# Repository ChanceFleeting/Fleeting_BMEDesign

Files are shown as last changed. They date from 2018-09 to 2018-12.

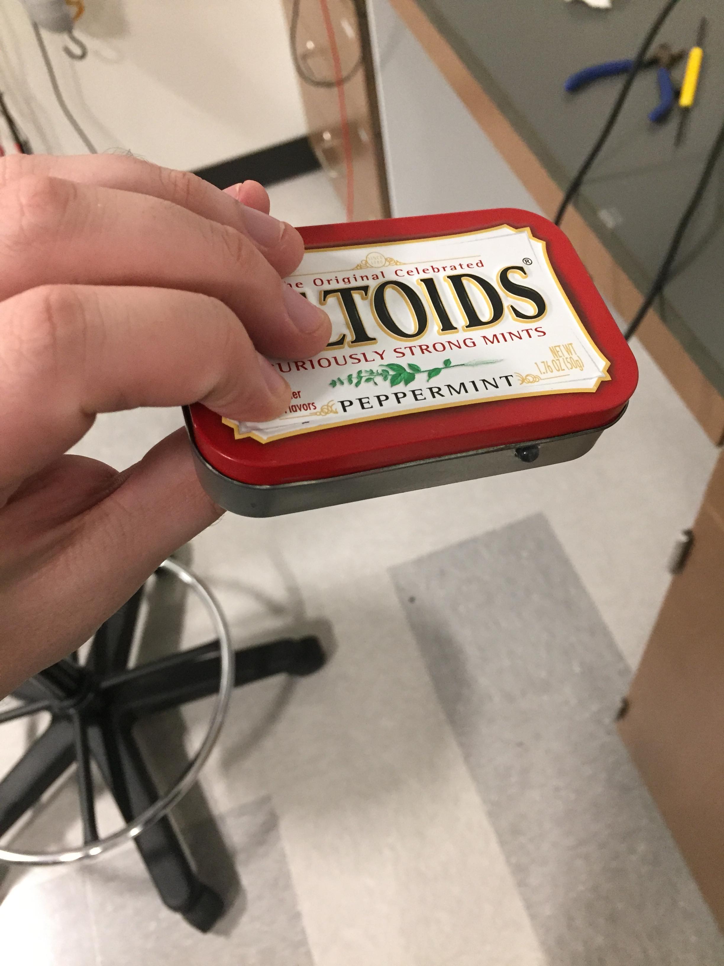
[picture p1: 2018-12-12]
Semester1Design/Testing/47689593_1096601613842765_1074258826393288704_n.jpg

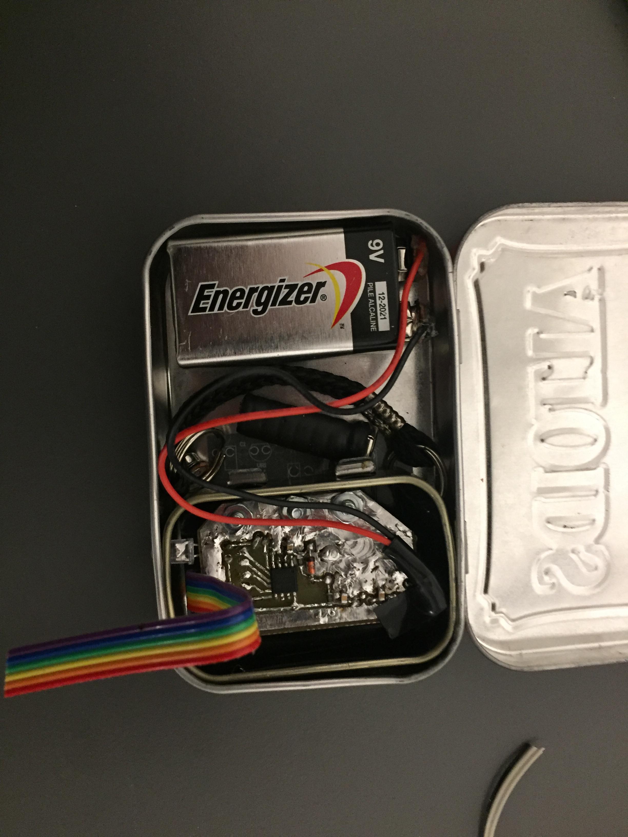
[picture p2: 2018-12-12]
Semester1Design/Testing/48209552_262310304441675_4003035783320567808_n.jpg

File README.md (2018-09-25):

# Fleeting_BMEDesign
A repo to contain my work for Dr. Palmeri's 2-semester BME design course (BME590L.03 F'18; BME464 Sp'19).
 
Semester 1 Design: Design Skills Project (Variable Light Intensity) 

    Functional Specifications
        LED light that is button-activated to switch between the following operating modes:
            Off
            Brightest
            Intermediate Brightness
            Least Bright
            Flashing @ 2 Hz
        Self-contained device with LED and button exposed.
        Extra credit possibilities:
            Battery life indicator
            Waterproof enclosure
            You tell us!

    Constraints

        Run on single battery up to 9 V
        Electronics connected to a single PCB (can be single- or double-sided)
        Cannot weight more than 1 lb
        Cannot have a single dimension > 6 in
        Cannot cost more than $50 to duplicate unit
        Battery must be easily replaceable

    Evaluation

        Minimize weight

        Minimize size

        Maximize Brightest mode

        Minimize power draw / maximize battery life

        Survive 3 foot drop with battery installed

        Create-and-maintain a GitHub project repository to maintain version history of:
            Mechanical CAD (PDFs + more)
            Electronic CAD (PDFs + more)
            Software
            Testing data
            Design history / notes
            Specification sheets
            Usage notes (README.md)
            Kanban board / Issues / Milestones

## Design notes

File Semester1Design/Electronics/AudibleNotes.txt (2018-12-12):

Changes made:

The TO92s were soldered below deck to allow for space ontop of device.
Ribbon cable has been replaced by female headers for reprogramability
100-Ohm resistor has been used as shunt to LED

EC:
Reprogramability
Modular design (minibattery broke (I sat on it))
Water proof (Still need to pot it in Nylon and coat the outside.
Thematic (Altoids please sponsor me)

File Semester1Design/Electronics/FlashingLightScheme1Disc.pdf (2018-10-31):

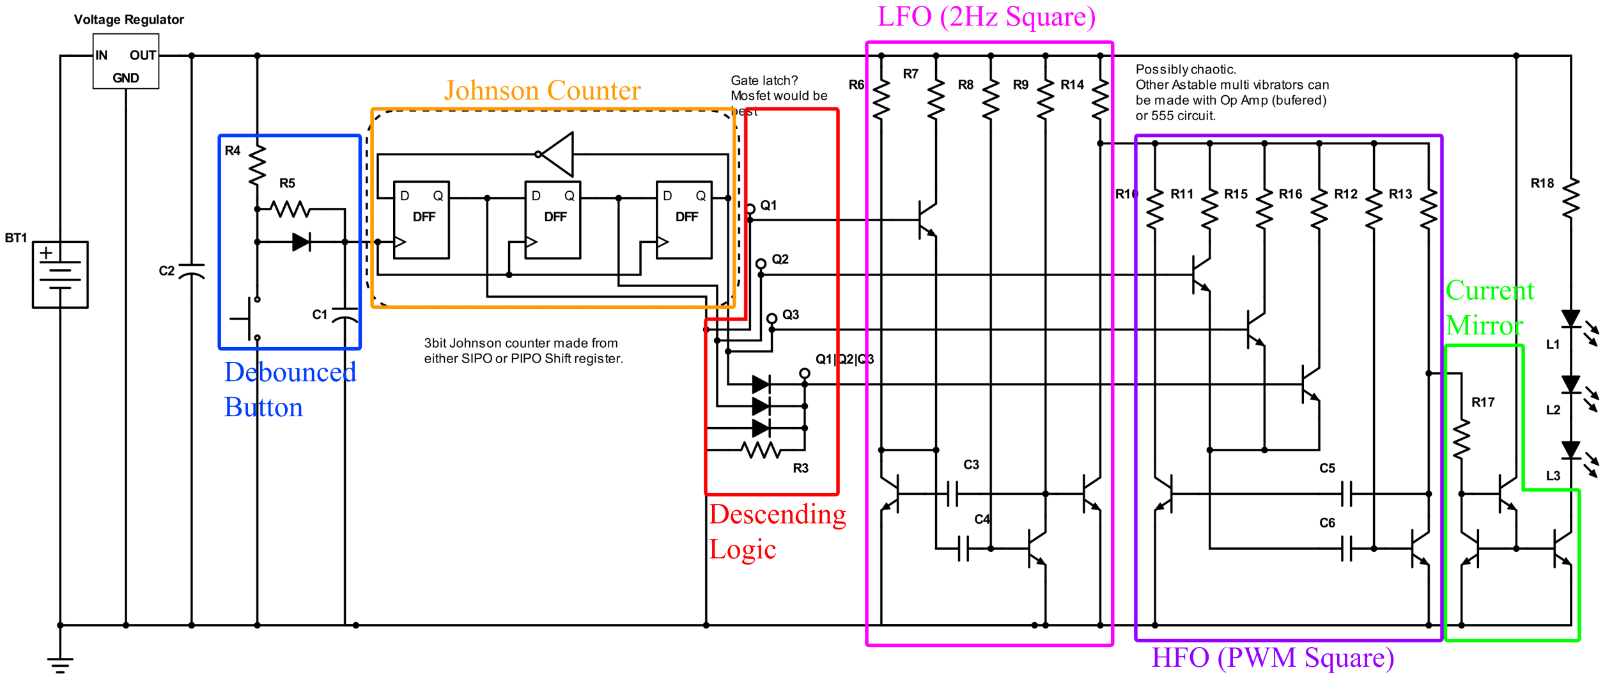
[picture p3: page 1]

Debounced
Button

HFO(PWMSquare)

Current
Mirror

JohnsonCounter

Descending
Logic

LFO(2HzSquare)

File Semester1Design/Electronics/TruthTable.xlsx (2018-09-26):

 |  |  | Truth Table: Descending logic from Manually Itterated Johnson Ring counter
 |  | Counter |  |  | Controls
 | State | Q1 | Q2 | Q3 | On/off | L 1 | L 2 | L 3 | Osc
off | 0 | 0 | 0 | 0 | 0 | 0 | 0 | 0 | 0
Low | 1 | 1 | 0 | 0 | 1 | 1 | 0 | 0 | 1
Mid | 2 | 1 | 1 | 0 | 1 | 1 | 1 | 0 | 1
High | 3 | 1 | 1 | 1 | 1 | 1 | 1 | 1 | 1
2HzH | 4 | 0 | 1 | 1 | 1 | 1 | 1 | 1 | 0
2HzM | 5 | 0 | 0 | 1 | 1 | 1 | 0 | 1 | 0
 |  | Descending Logic |  |  | Q1|Q2|Q3 | Q1|Q2|Q3 | Q2 | Q3 | Q1

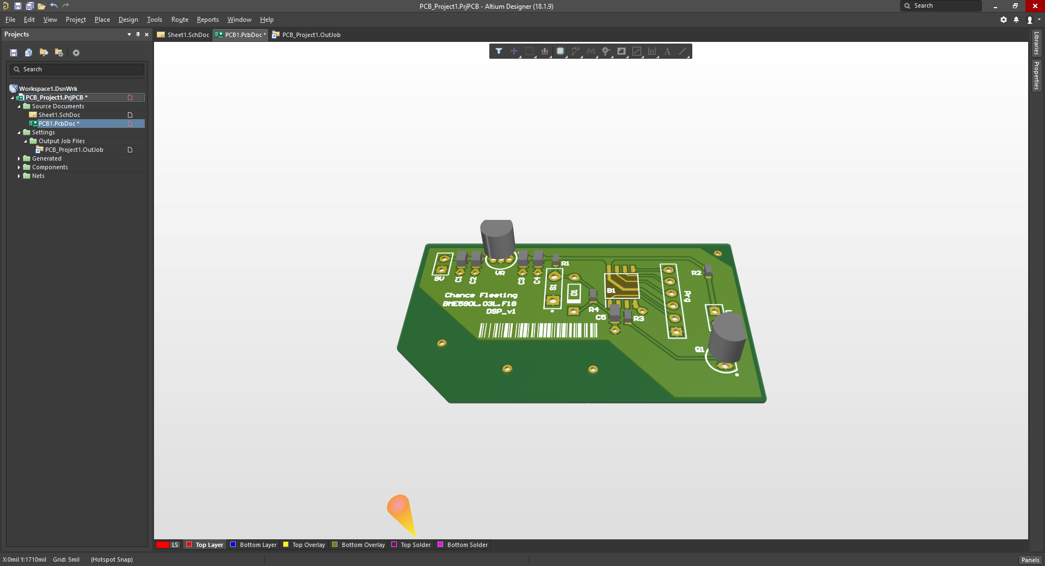
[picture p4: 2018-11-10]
Semester1Design/Electronics/PCB/PCB_3D_Front.PNG

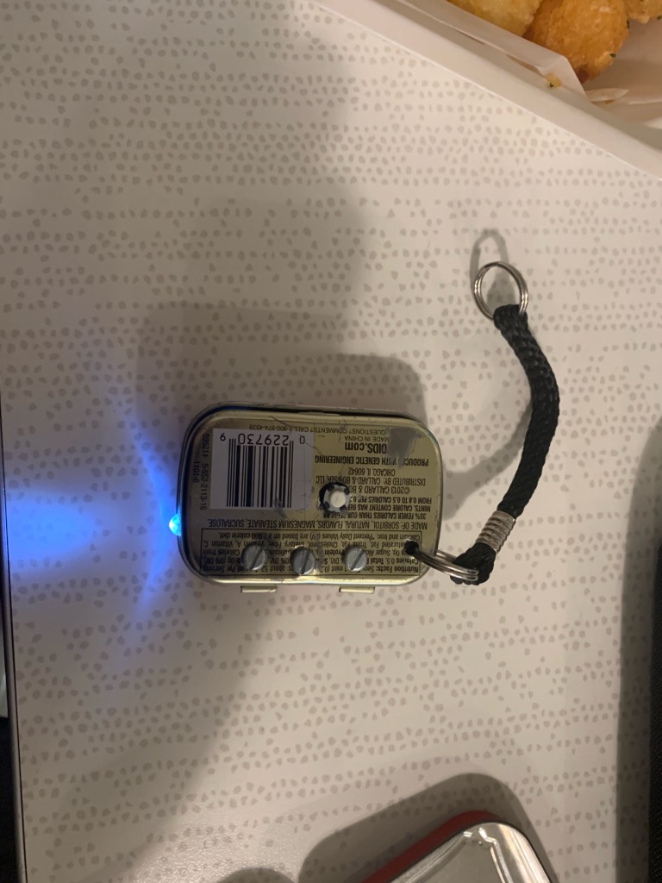
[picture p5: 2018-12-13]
Semester1Design/Testing/Final_Design_Small_3.jpg

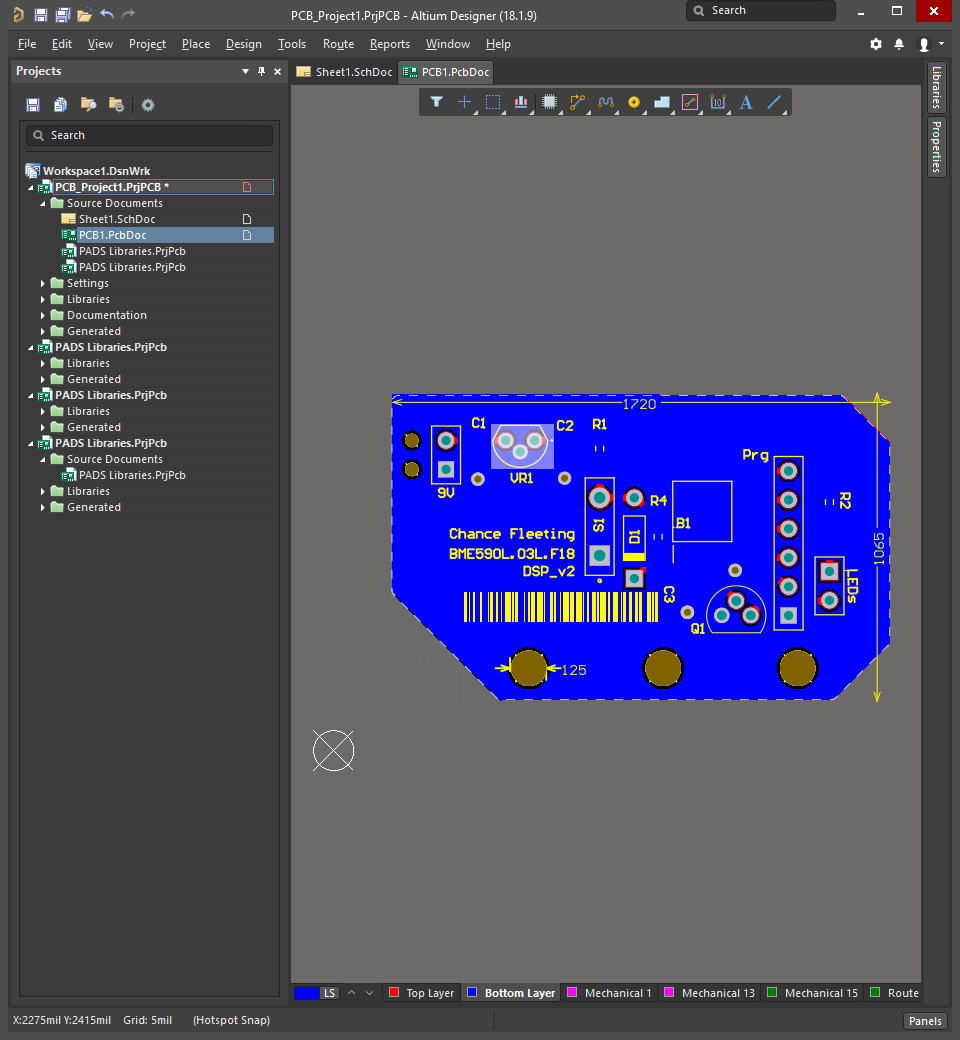
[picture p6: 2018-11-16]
Semester1Design/Electronics/PCB/PCB_2D_Back_smaller.PNG

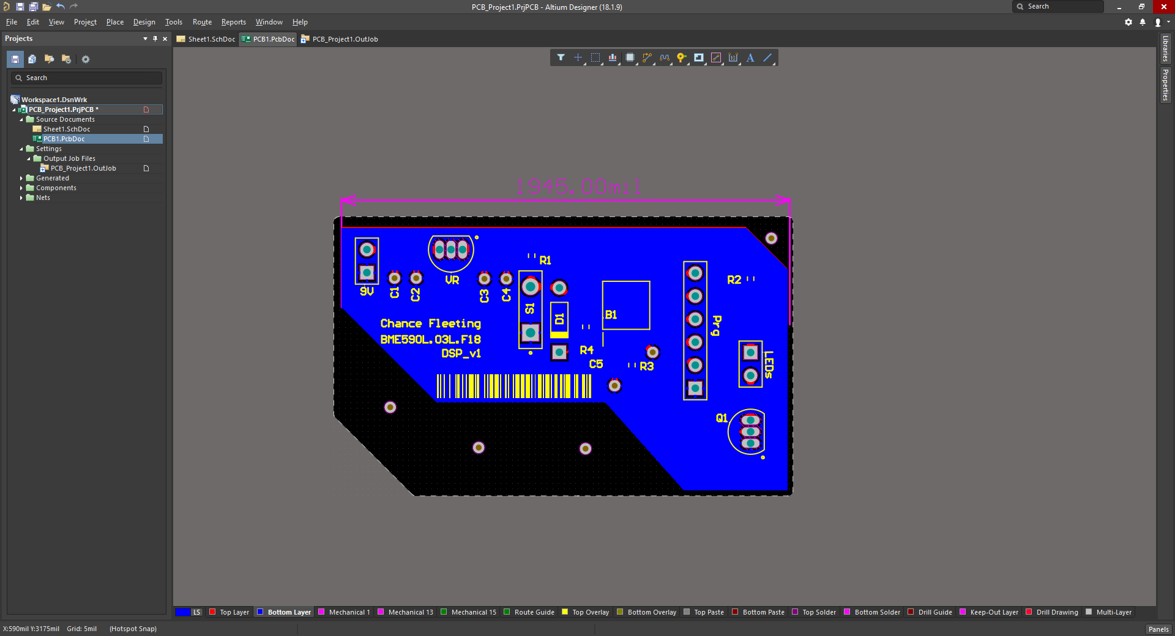
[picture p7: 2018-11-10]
Semester1Design/Electronics/PCB/PCB_2D_Back.PNG

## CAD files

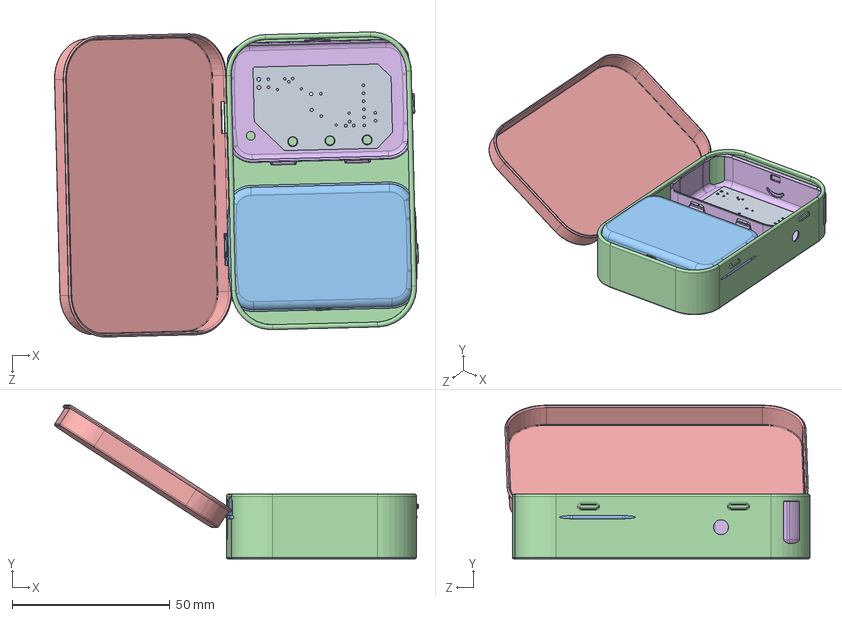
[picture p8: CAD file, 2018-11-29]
Semester1Design/Mechanical/CasingExploration/Assem1.SLDASM
115.5 x 48.8 x 96.8 mm
Board
9V
smallLid
Bottom
Lid
smallBottomCut

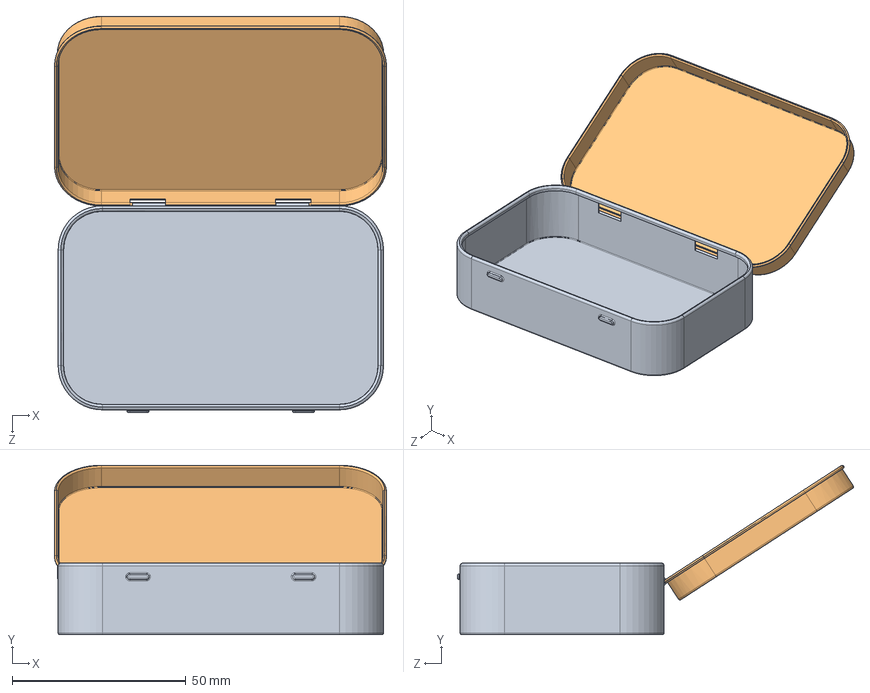
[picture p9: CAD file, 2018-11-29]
Semester1Design/Mechanical/CasingExploration/LargeAltoidsbox.SLDASM
95.6 x 48.8 x 114.1 mm
Bottom
Lid

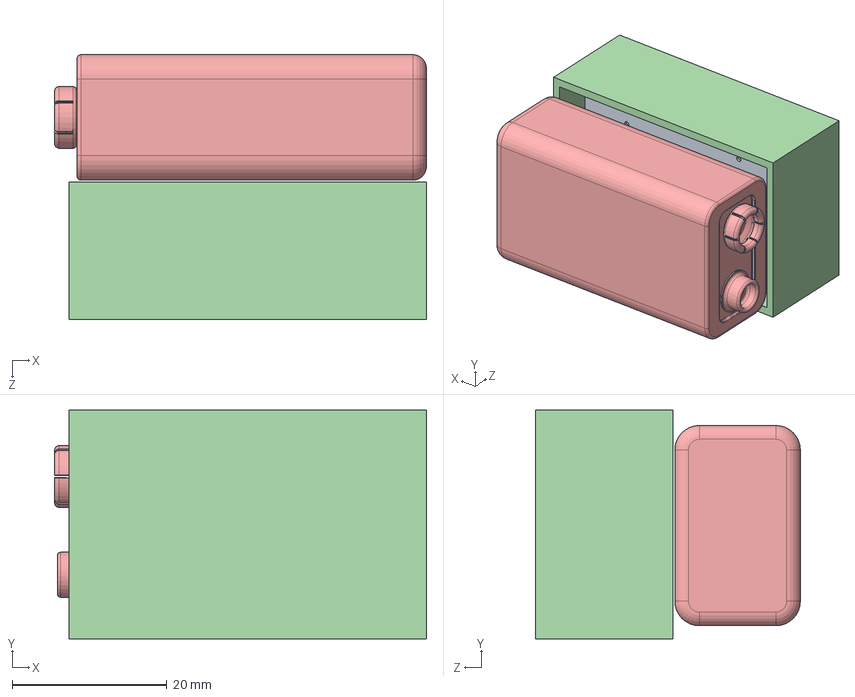
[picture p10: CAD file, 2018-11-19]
Semester1Design/Mechanical/PCB1.SLDASM
48.1 x 29.6 x 34.3 mm
Board
Extruded x 3
Extruded_2 x 3
9volt

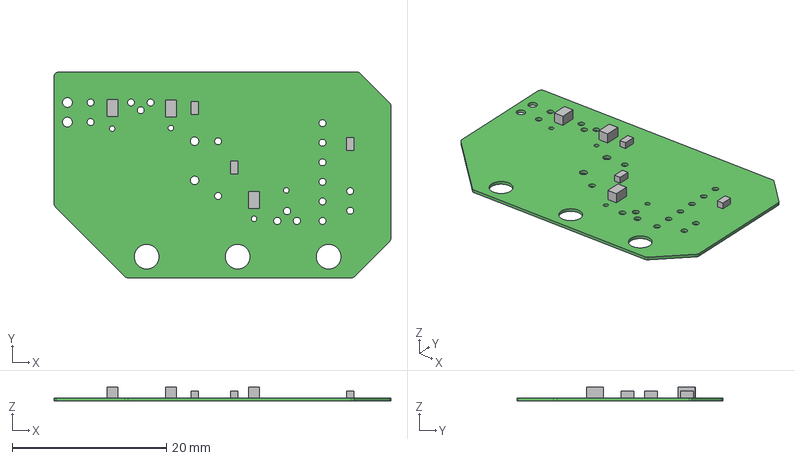
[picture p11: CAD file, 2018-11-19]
Semester1Design/Electronics/PCB/ECAD files/PCB1.step
43.7 x 26.7 x 1.81 mm
Board
Extruded x 6

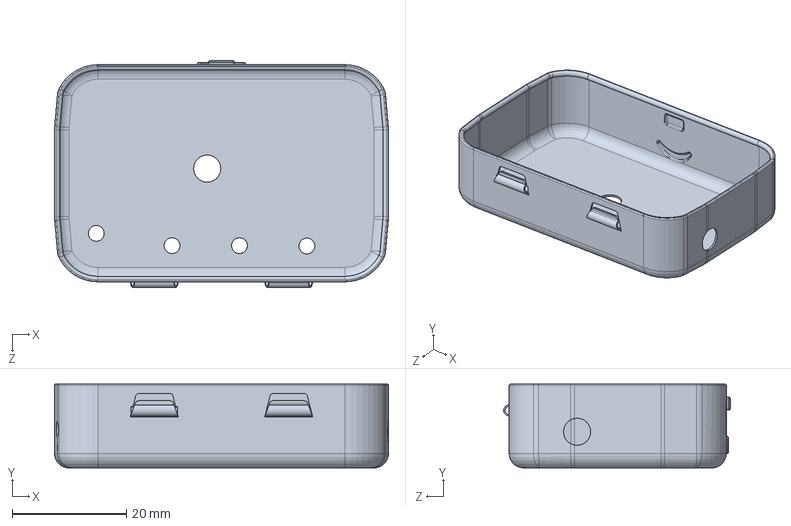
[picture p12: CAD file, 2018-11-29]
Semester1Design/Mechanical/CasingExploration/smallBottomCut.SLDPRT
58.5 x 14.7 x 39.7 mm

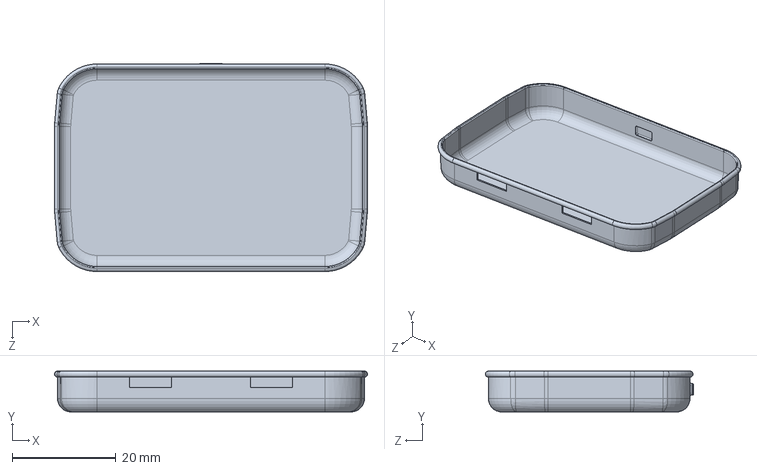
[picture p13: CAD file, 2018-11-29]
Semester1Design/Mechanical/CasingExploration/smallLid.SLDPRT
60.4 x 7.87 x 40.2 mm

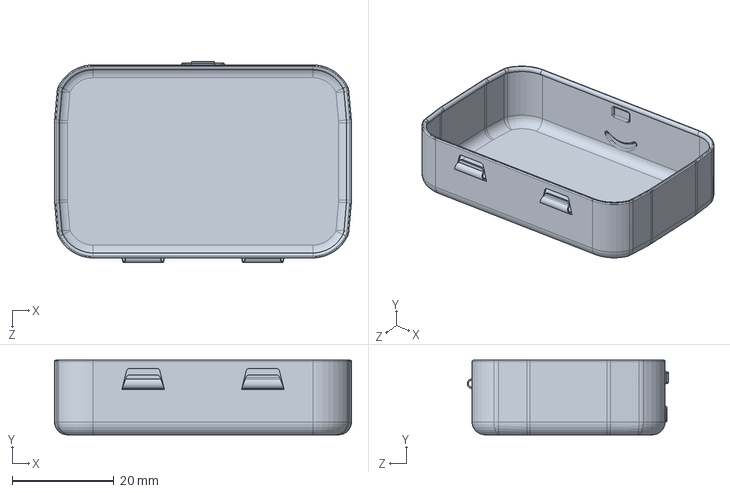
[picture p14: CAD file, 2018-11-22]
Semester1Design/Mechanical/CasingExploration/smallBottom.SLDPRT
58.5 x 14.7 x 39.7 mm

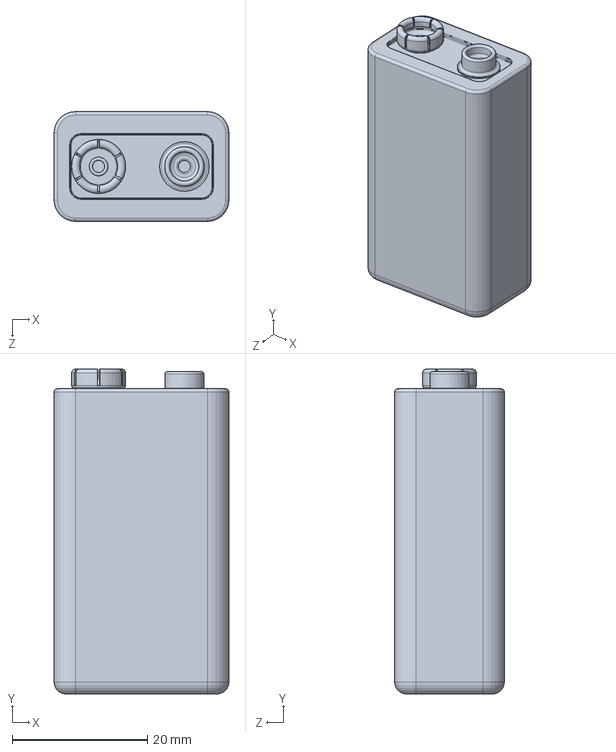
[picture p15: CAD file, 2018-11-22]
Semester1Design/Mechanical/CasingExploration/9V.SLDPRT
25.9 x 48.1 x 16.3 mm

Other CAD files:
Semester1Design/Mechanical/R2.sldasm
Semester1Design/Mechanical/C2.sldasm
Semester1Design/Mechanical/R1.sldasm
Semester1Design/Mechanical/C1.sldasm
Semester1Design/Mechanical/R4.sldasm
Semester1Design/Mechanical/C3.sldasm
Semester1Design/Mechanical/Board.sldprt
Semester1Design/Mechanical/Extruded.sldprt
Semester1Design/Mechanical/Extruded_2.sldprt
Semester1Design/Mechanical/5803305728.sldasm
Semester1Design/Mechanical/5803305536.sldasm
Semester1Design/Mechanical/SpecialAssembly.SLDDRW

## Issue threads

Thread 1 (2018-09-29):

Interface Controls: style and count

ChanceFleeting, 2018-09-29:
In the instruction it is stated that the variable light will need to be “button-activated to switch between [five] operating modes“. Does this mean that we are expected to have a _single_ button as the full control interface rather than individual controls or are we allowed to use separate tunable controls for all parameters (ie analog controls such as switches and potentiometers)?

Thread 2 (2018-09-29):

IC: limitations and Expectations

ChanceFleeting, 2018-09-29:
Is there a limit on what ICs we can use? If we were expected to use a single button, I was going to connect it to a ring counter to iterate through states (I’m working relatively hard to avoid using a microprocessor for this application) in conjunction to limited control logic, but such a system would be relatively laborious to manually build out of discrete transistors. Using specific ICs for such a task would be pretty helpful.

That also being said, would we (realistically) have an opportunity to use, apply, and print some sort of HDL-synthesis technique to print our own integrated circuit with embedded transistors for this type? It would be really cool to focus this circuit down to the minimum basics that I would need.

mlp6, 2018-10-01:
The IC is not specified in any way, so you have a wide-open playing field for that.  There is the imposed constraint of using a single button though.  Avoiding the use of an MCU is a good starting point; that would be an 800 lb gorilla for this problem, though it is a viable solution.

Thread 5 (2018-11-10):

Milestone 4: ECAD Itteration 1

ChanceFleeting, 2018-11-10:
I'm sorry this is late. It has been a crazy week.
My current Itteration of the base design:
https://github.com/ChanceFleeting/Fleeting_BMEDesign/tree/master/Semester1Design/Electronics/PCB

ChanceFleeting, 2018-11-10:
I will @sphearobolus as soon as my collaboration request is returned

sphaerobolus, 2018-11-14:
board looks good to me*. In the schematic, I'd replace the misleading BJT symbol with one that better represents your voltage regulator.

*Just make sure the voltage regulator in the TO-92 case can supply the current you need. I'm pretty sure it can, but make certain.

ChanceFleeting, 2018-11-14:
@sphaerobolus, for the TO-92 package of the 7805, is the model that we are working with the same thing as LM78L05? If so, the Io seems to be 40mA (I attached a source below p2) , which should be good according to what I observed on Monday. Also, I definitely agree with the fact I should replace the BJT symbol. I left it in there so that I would have the right footprint for the TO92 case. I will fix that in this iteration.

Thank you!

LM78L05: http://users.ece.utexas.edu/~valvano/Datasheets/LM78L05.pdf

sphaerobolus, 2018-11-14:
the 78L05 is, indeed, what we have.

ChanceFleeting, 2018-11-14:
Thank you!
I have fixed and adjusted the Schematic and PCB:
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

I'm also looking at bumping my trace widths. Right now I have 20 mil for the power line and 10 mil for the signal lines.

Linked: https://github.com/ChanceFleeting/Fleeting_BMEDesign/blob/master/Semester1Design/Electronics/PCB/ECAD%20files/PCB_Project1.pdf

ChanceFleeting, 2018-11-21:
@mlp6 and @sphaerobolus  Is there any  adjustments I need to make on my PCB before it is ready to print?

Linked: https://github.com/ChanceFleeting/Fleeting_BMEDesign/blob/master/Semester1Design/Electronics/PCB/ECAD%20files/PCB_Project1.pdf

sphaerobolus, 2018-11-22:
looks good!

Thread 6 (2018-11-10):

EC feasibility.

ChanceFleeting, 2018-11-10:
I want to test out 2 auxiliary subcircuits this week before I implement them. So you should see me in lab soon.
1.) A soft latch circuit that allows for controlled shut down (by the ATtiny) as well as a force shut down (hold off/press on).

2.) A power monitor which turns on a light when the battery goes below some power threshold.

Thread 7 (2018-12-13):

Milestone 4: Demos

ChanceFleeting, 2018-12-13:
https://github.com/ChanceFleeting/Fleeting_BMEDesign/tree/master/Semester1Design/Testing/Demos

I am keeping a running issue related to Testing Demos and information. I may add some more demos. I'm still cleaning stuff up and compiling documentation in the repo, but I need to divert my attention to studying.

Extra Features:
Reprogramability (Female pin headers on top of board)
Modular adaptive design:
              small Altoids tin version-- uses specialty 9-V battery (homemade) and is very small
              large Altoids tin version-- uses standard 9-V battery, but is larger
Thematic (Altoids theme has been maintained)
*Not Implemented*: Water Proofing (epoxy potting and nail polish coating)

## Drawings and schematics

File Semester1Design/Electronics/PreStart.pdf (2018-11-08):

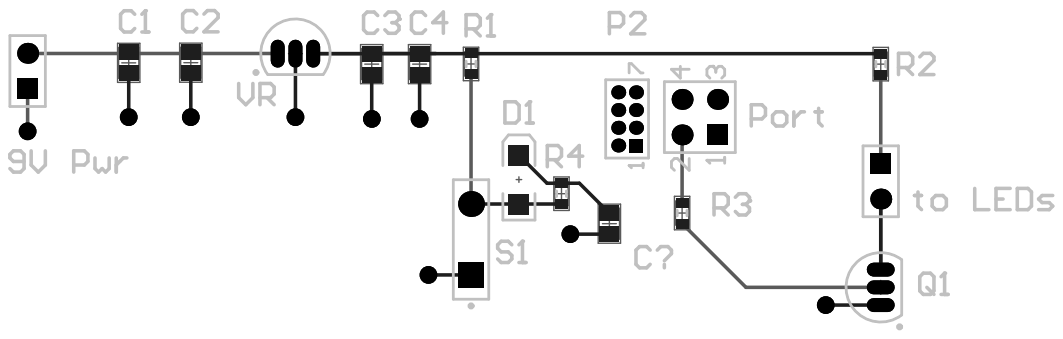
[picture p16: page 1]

Board S

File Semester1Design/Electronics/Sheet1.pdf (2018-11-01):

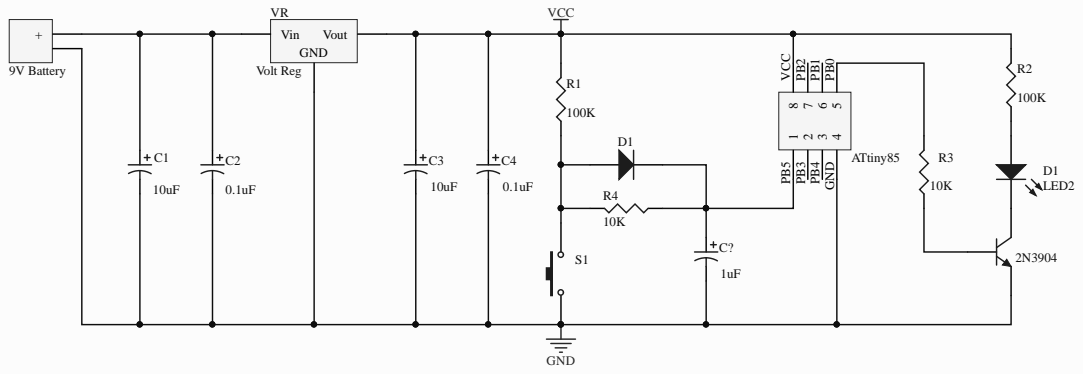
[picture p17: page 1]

# Board S

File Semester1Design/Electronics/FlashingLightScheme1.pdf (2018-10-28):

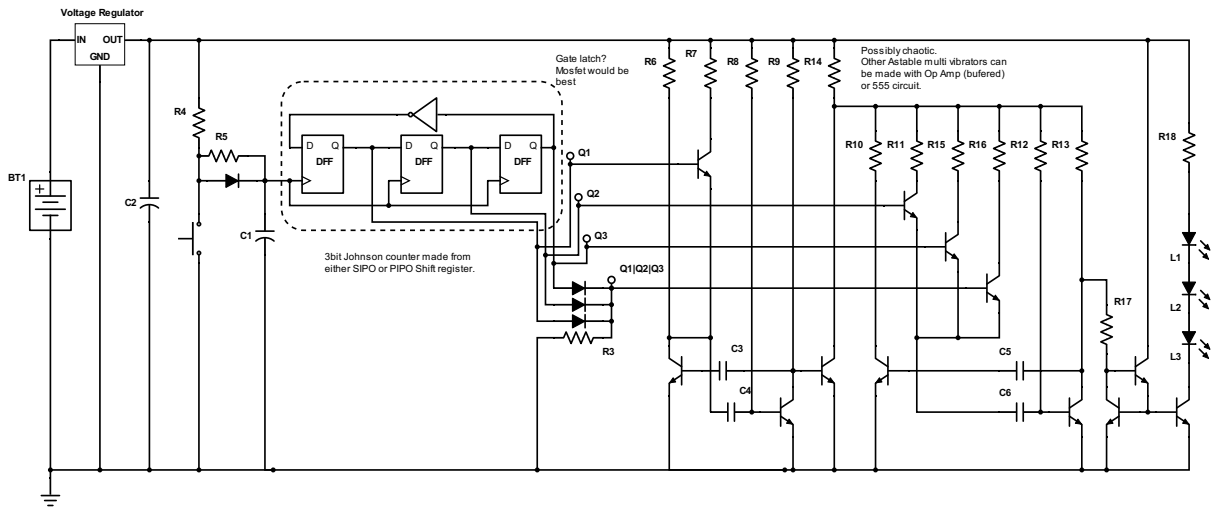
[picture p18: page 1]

Possiblychaotic.
Other Astable multi vibrators can
be made with Op Amp (bufered)
or 555 circuit.

Mosfet would be best

3bit Johnson counter made from
either SIPO or PIPO Shift register.

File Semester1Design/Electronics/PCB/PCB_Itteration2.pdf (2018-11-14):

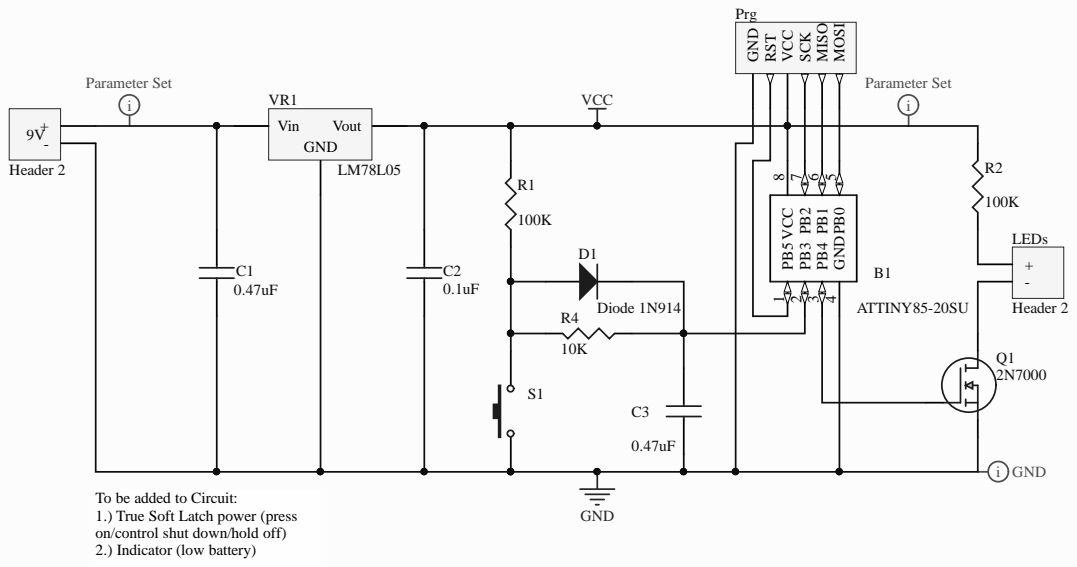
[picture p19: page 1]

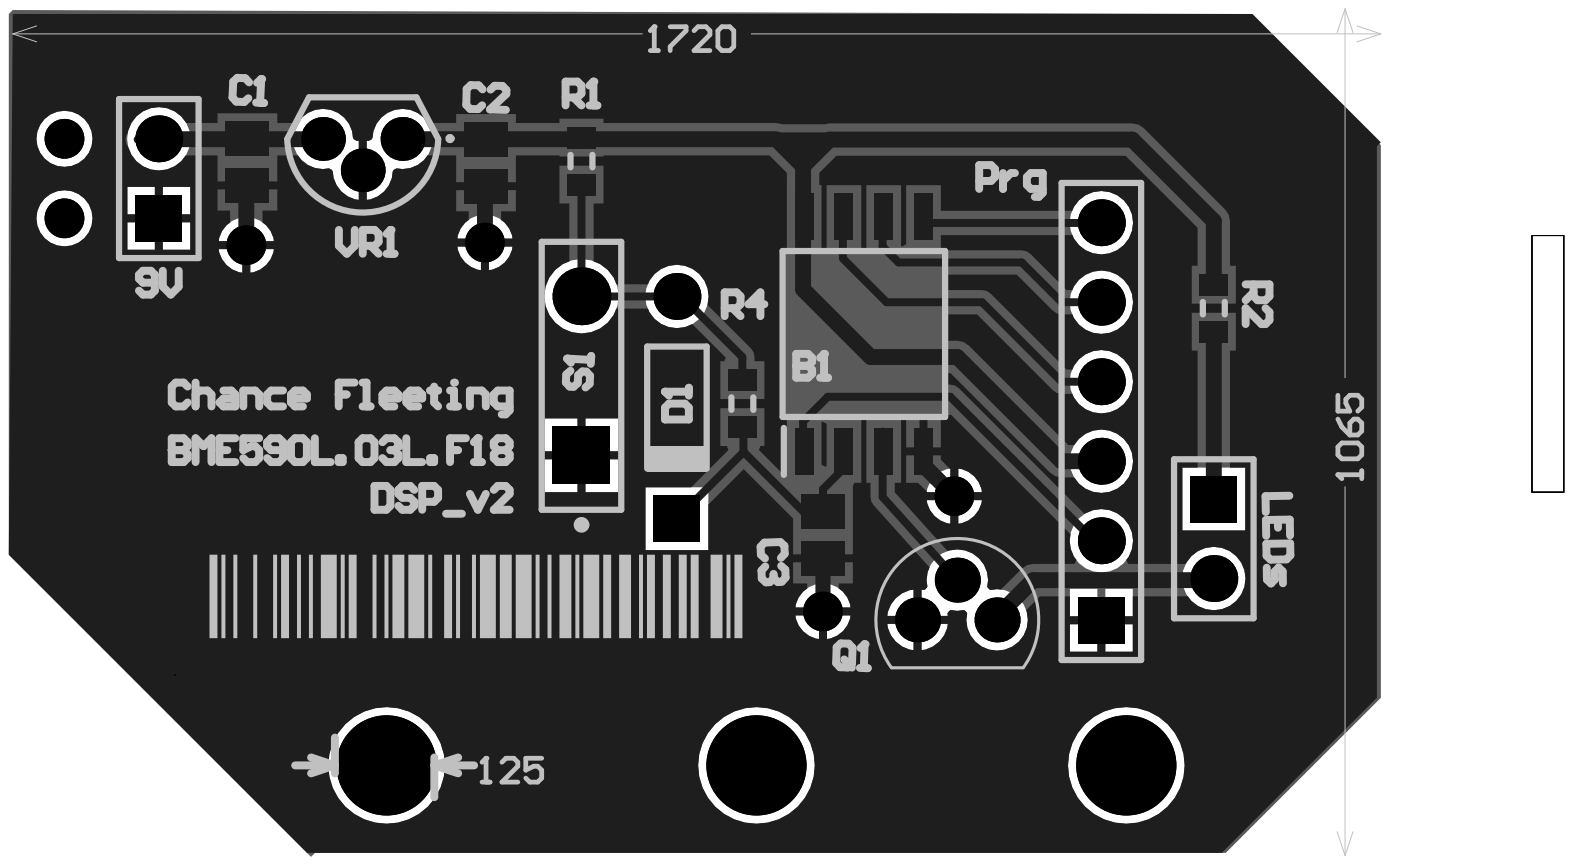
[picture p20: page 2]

# Board S

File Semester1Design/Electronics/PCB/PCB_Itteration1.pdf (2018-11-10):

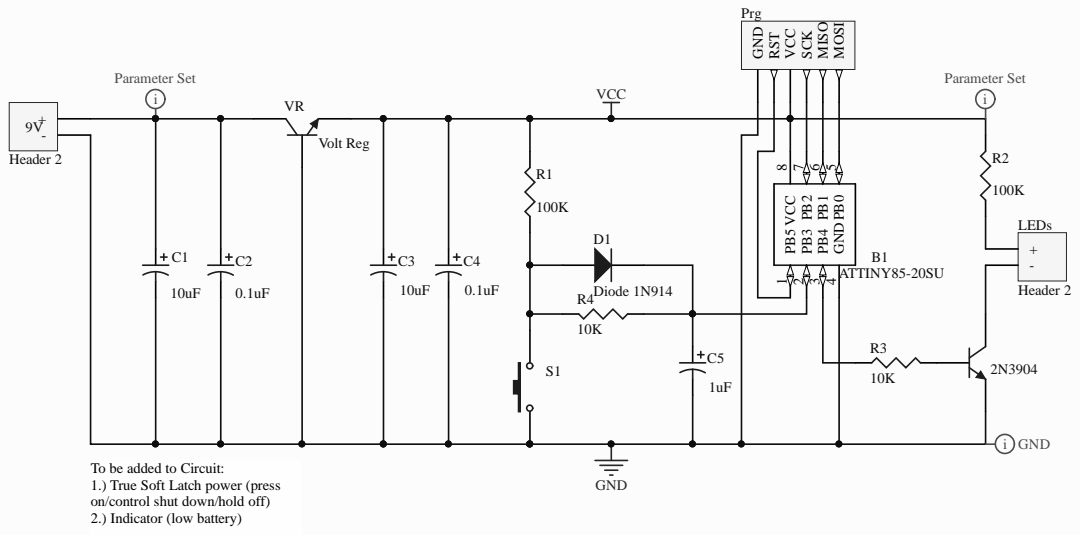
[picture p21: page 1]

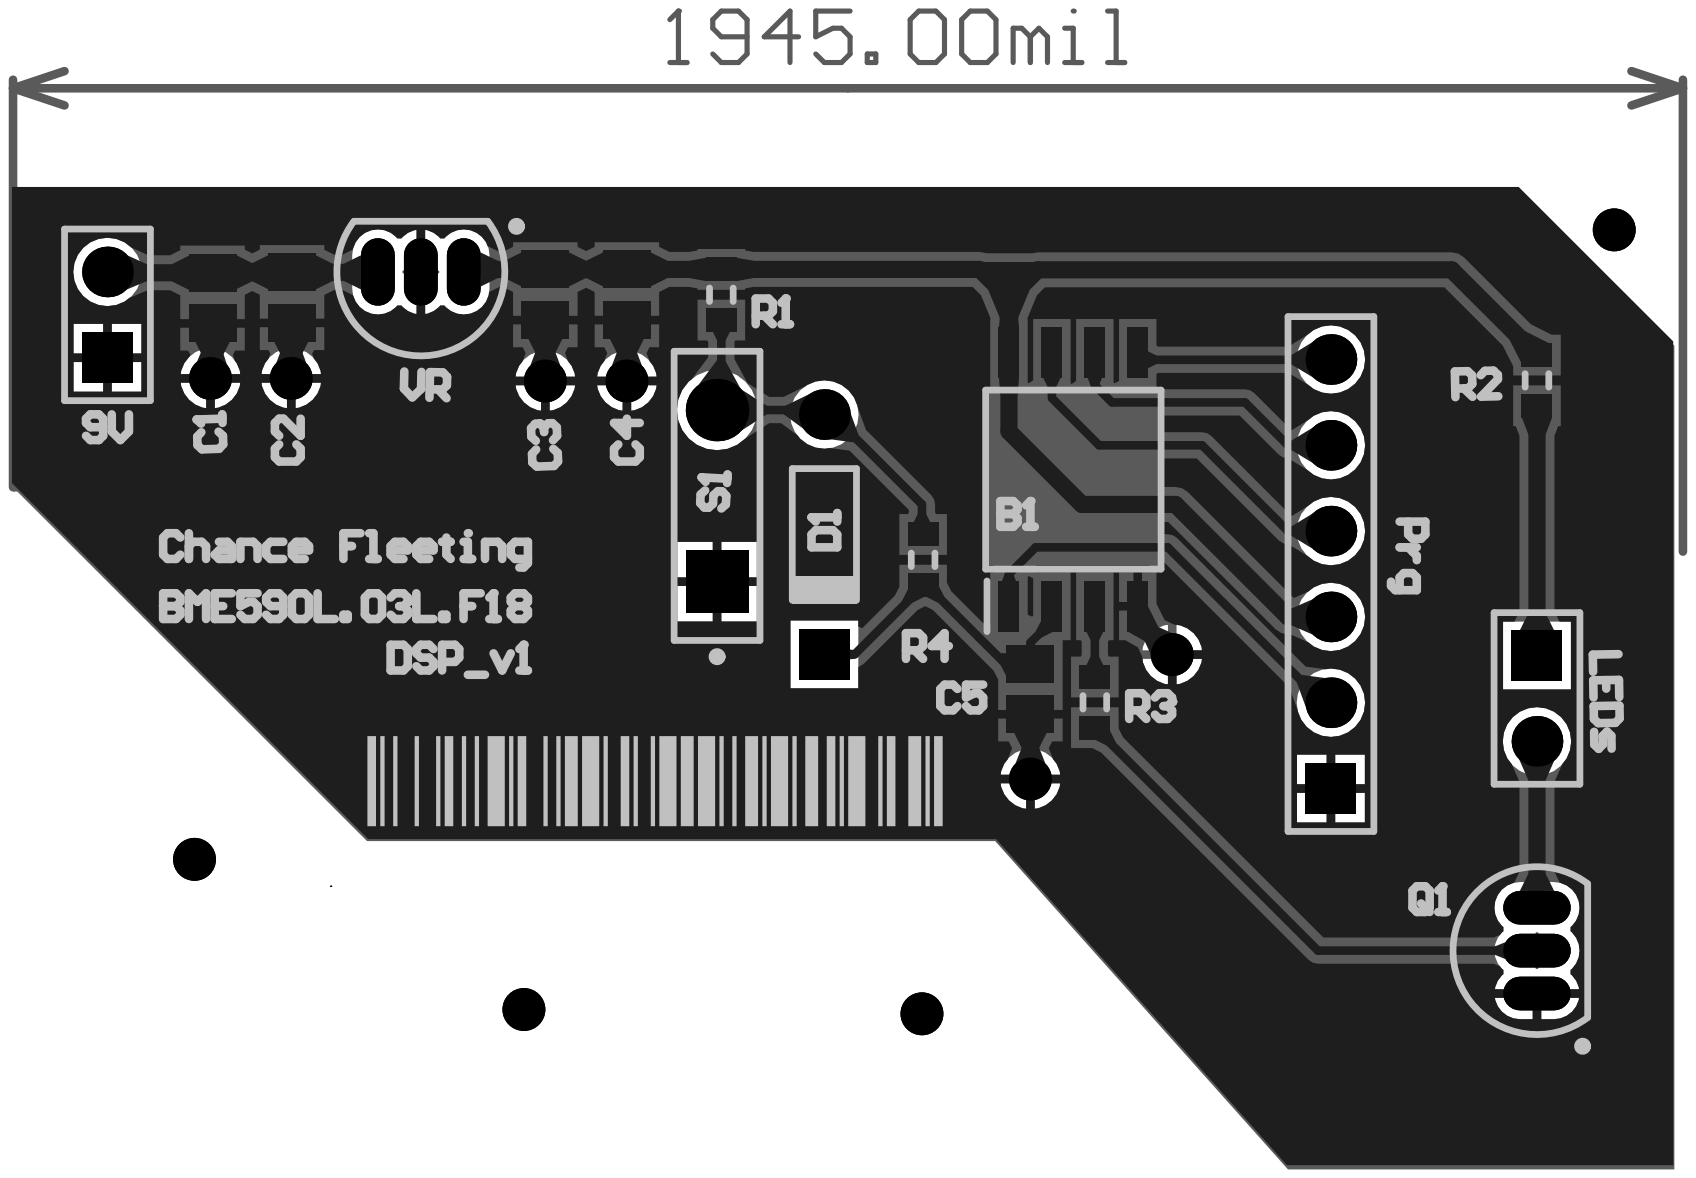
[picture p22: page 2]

# Board S

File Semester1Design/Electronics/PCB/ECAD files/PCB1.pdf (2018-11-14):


Board S

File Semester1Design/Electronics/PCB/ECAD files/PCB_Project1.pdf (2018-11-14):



# Board S

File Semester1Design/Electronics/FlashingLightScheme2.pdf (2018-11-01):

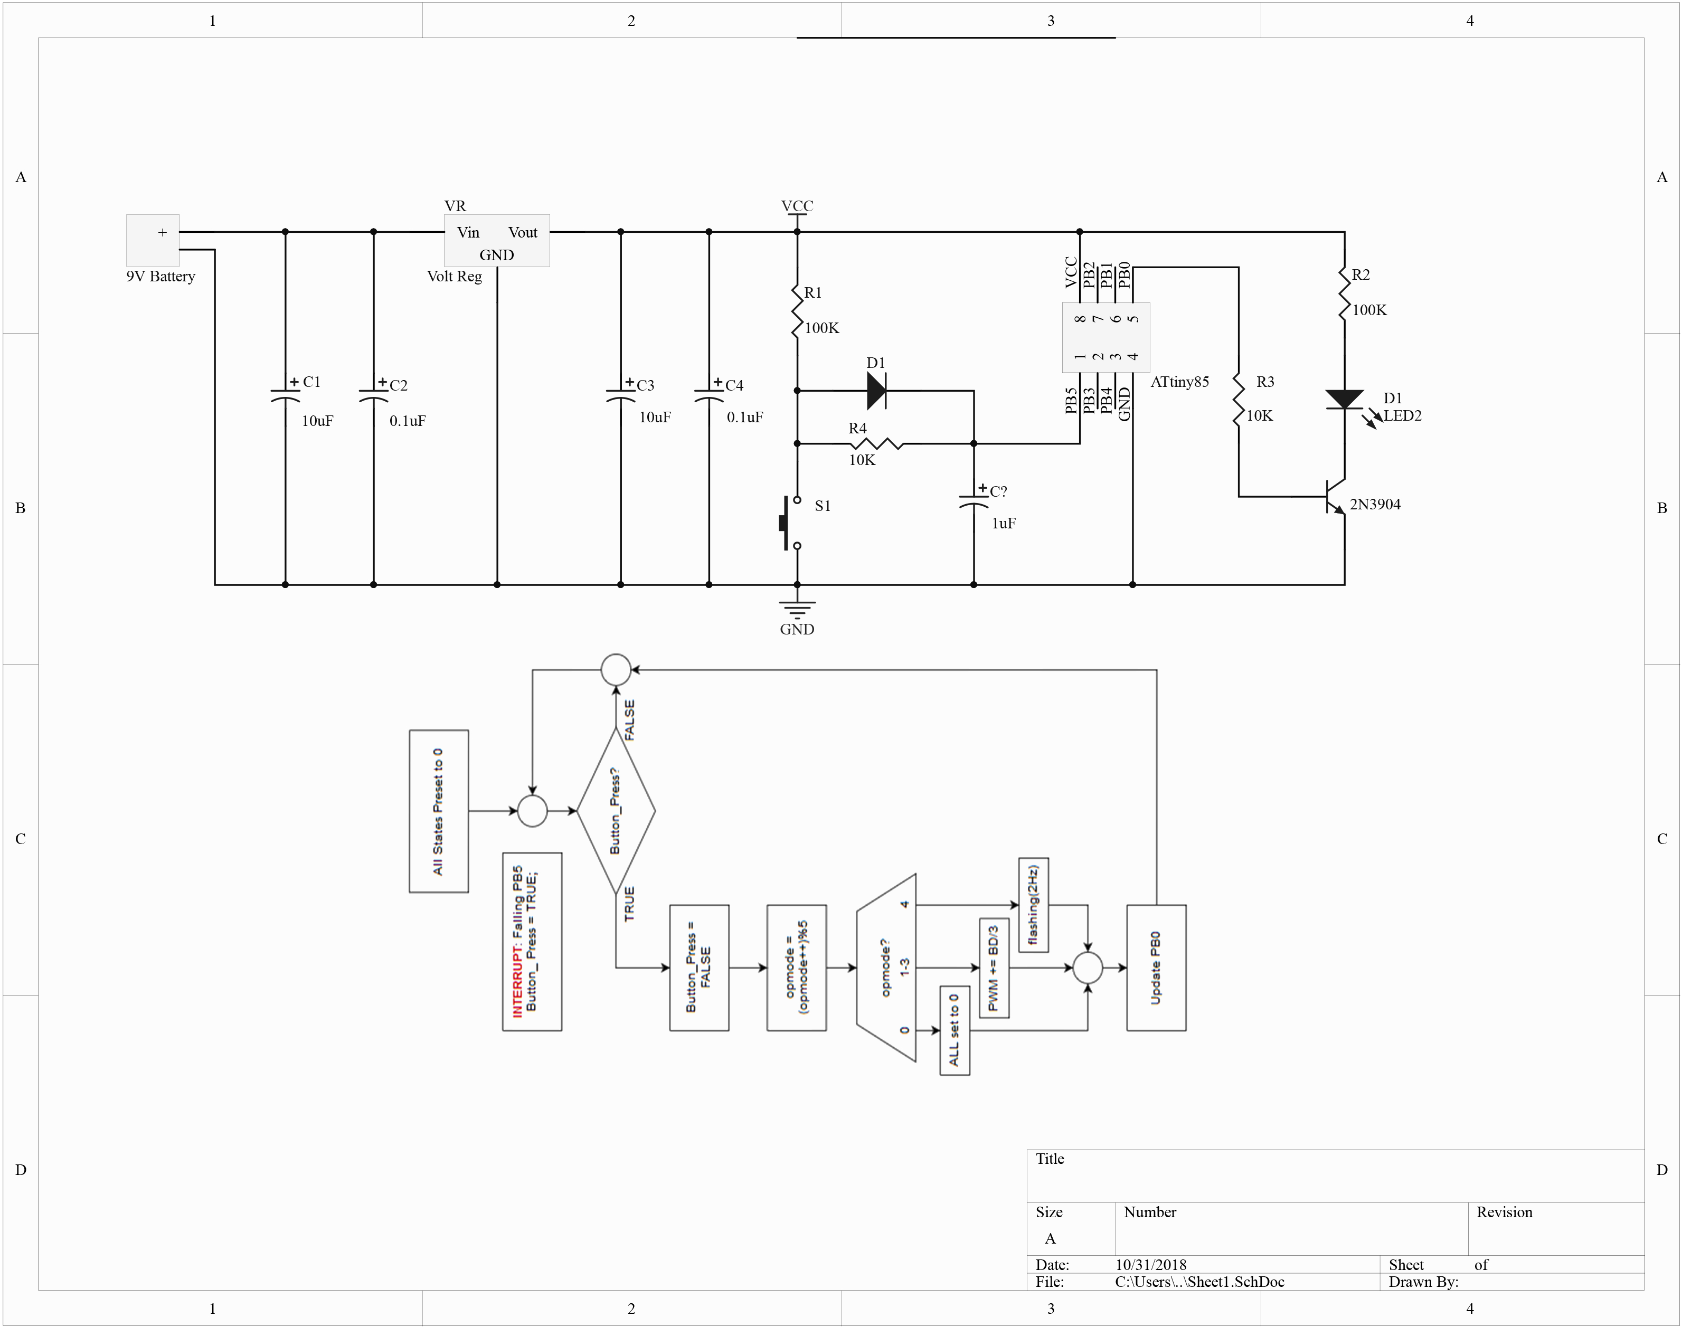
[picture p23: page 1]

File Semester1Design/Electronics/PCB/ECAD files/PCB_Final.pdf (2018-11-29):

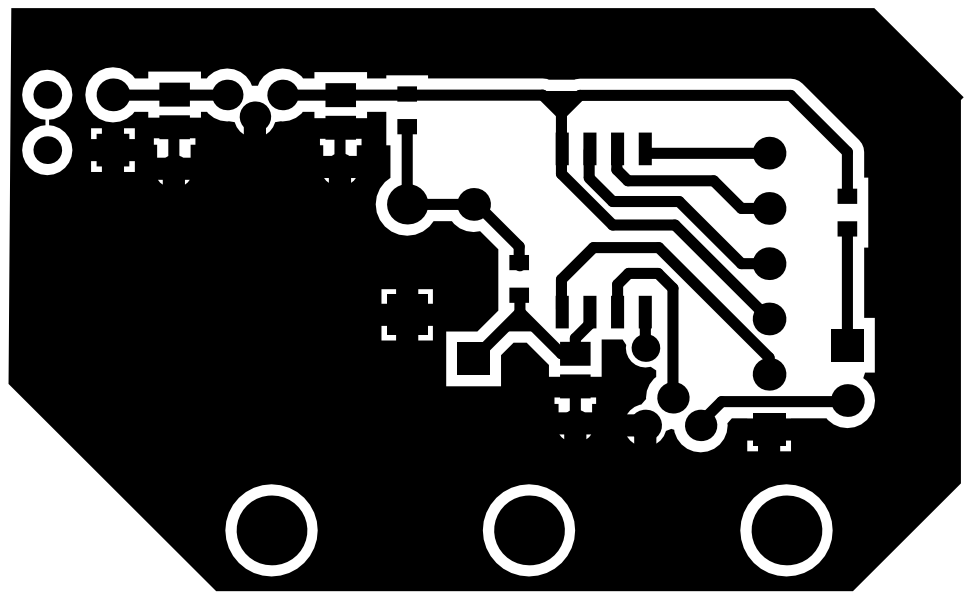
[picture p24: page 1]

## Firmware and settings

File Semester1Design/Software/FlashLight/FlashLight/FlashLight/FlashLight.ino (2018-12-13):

/* Blinking Flashlight Code
 version 3
 
 Chance Fleeting (crf37) 12/11/18

 References:
 While this is my own work, this code was developed through a process referencing
 online resources and open discussion with peers. Such peers include Gregory Goldman
 (ghg3) and Jason Fischell (jnf22). Sources include the following:
 [1] http://ww1.microchip.com/downloads/en/devicedoc/atmel-2586-avr-8-bit-microcontroller-attiny25-attiny45-attiny85_datasheet.pdf
 [2] https://www.nongnu.org/avr-libc/user-manual/io_8h_source.html
 [3] https://www.nongnu.org/avr-libc/user-manual/group__avr__interrupts.html
 [4] https://www.nongnu.org/avr-libc/user-manual/group__avr__sleep.html
 [5] https://playground.arduino.cc/Main/AVR
 [6] https://thewanderingengineer.com/2014/08/11/pin-change-interrupts-on-attiny85/
*/
// Dependancies
#include <avr/io.h>                                         // AVR Interface with the hardware [2]
#include <avr/interrupt.h>                                   // AVR Interrupt library [3]
#include <avr/sleep.h>                                      // AVR Sleep-mode library [4]

// Definitions [4]

int OPIN = 4;
int IPIN = 3;
bool Flash = LOW;
volatile bool swtch = HIGH;
const unsigned long T = 500; // Flash Period (ms)
unsigned long to = 0; //current time
unsigned long t1 = 0; // previous time
int State = 0;
/*
   0: off
   1: low
   2: med
   3: high
   4: 2Hz blink at high intensity
*/

void setup() {
  // Disable interrupt
  cli();
  // Register Initialization [1] p 64. I prefer Hex over Bin.
  PORTB = (~((1 << OPIN) | (1 << IPIN)));                   // Internal Pull-up is disabled for the nonfloating I/O pins (IPIN and OPIN)
  DDRB  = (1 << OPIN);                                      // Set OPIN to output (this is the LED Driver)
  PINB = 0x00;                                              // From Greg's code. Unnecessary but no harm.
  // interrupt Initialization [1] p 49
  GIMSK = 0x20;                                                // Global staging: Turns on pin interrupt capability [1] p200
  PCMSK = (1 << IPIN);                                      // Set IPIN to input-- interrupt (this is debounced button)
  // Shut Down ADC (Greg's Suggestion to save power)
  ADCSRA &= ~_BV(ADEN);                                      //if ADEN is on, turn off.
  // Enable interrupt
  sei();
}

void loop() {
  if (swtch) {
    SwitchStates();                                     //  If triggered, itterate forward in states
  }
  analogWrite(OPIN, Flash?((4<<(State<<1))-1):0);       // if Flash boolean, use pwm == 4^(1+State)-1, else off
  if (State == 4) {
    FlashMode();                                        //Flashmode activated
  }
  if (State == 0) {
    SleepMode();                                        //Sleepmode activated
  }
}

/* SwitchStates():
 *  Activates Flash Mode (activated by swtch)
 *  5-step counter. Defaults Flash and resets swtch.
 */
void SwitchStates(){
    State = (++State)%5;
    Flash = !(State == 0);
    swtch &= LOW;
}

/* FlashMode():
 *  Activates Flash Mode (activated State == 4)
 *  Toggle alternator using internal clock.
 */
void FlashMode(){
      to = micros();
      if (to - t1 > T*500) {
        Flash = !Flash;
        t1 = to;
      }
}

/* SleepMode():
 *  Activates Sleep Mode (activated State == 0)
 *  Saves Power
 */
void SleepMode(){
      set_sleep_mode(SLEEP_MODE_PWR_DOWN);
      sleep_enable();
      sleep_cpu();
}

/* Interrupt:
 *  Switches Boolean, which allows for change in state
 */
ISR(PCINT0_vect) {                                            // Respond on pin change (Rise | Fall)
  //Pin Change Interrupt Request 0 [3] No Nesting interrupts
      swtch |= !digitalRead(IPIN);              // ~High Respond -> Falling Edge; Turn on swtch state
}

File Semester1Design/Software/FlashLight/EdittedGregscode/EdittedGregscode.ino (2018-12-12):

/*
 * FinalFlashlightCode.ino
 * Greg Goldman
 * BME 590: Medical Instrumentation Design
 * Fall, 2018
 * 
 * This code operates a flashlight on an ATTiny85 processor at a clock speed of 8 MHz
 * It is capable of 5 modes: low, medium, high, flash at high, and off
 * When off, the processor is put to sleep, reducing its current draw from a few mA
 * to less than 50 uA.
 * 
 * It uses interrupts to record button inputs, and it has rudimentary software debounce 
 * built in.
 * 
 * A great challenge with the debounce was that the timer resets after going to sleep, so
 * it was hard to tell the time since the last press if the device had slept. This was solved
 * by implementing a delay of the bounce wait time before going to sleeep. 
 * 
 * All time variables are in microseconds because micros() works in the ISR, but millis doesn't
 * 
 * In an unsigned long, there are 2^32 bits, so I can count to about 4.295 billion microseconds,
 * or about 4295 seconds, which is about 2.98 days before the timer count can roll over
 * 
 * Related content can be found at https://github.com/GregGoldman/BlinkLight
 */

//Includes
#include <avr/io.h> 
#include <avr/interrupt.h> //https://www.nongnu.org/avr-libc/user-manual/group__avr__interrupts.html
#include <avr/sleep.h> //https://www.nongnu.org/avr-libc/user-manual/group__avr__sleep.html
//https://bigdanzblog.wordpress.com/2014/08/10/attiny85-wake-from-sleep-on-pin-state-change-code-example/
// how to put attiny to sleep

int OPIN = 4;
int IPIN = 3;
bool Flash = LOW;
volatile bool swtch = HIGH;
unsigned long now = 0; //current time
unsigned long lastFlashTime = 0; // previous time
int State = 0;
/*
   0: off
   1: low
   2: med
   3: high
   4: 2Hz blink at high intensity
*/

void setup() {
  // Disable interrupt
  cli();
  // Register Initialization [1] p 64. I prefer Hex over Bin.
  PORTB = (~((1 << OPIN) | (1 << IPIN)));                   // Internal Pull-up is disabled for the nonfloating I/O pins (IPIN and OPIN)
  DDRB  = (1 << OPIN);                                      // Set OPIN to output (this is the LED Driver)
  PINB = 0x00;                                              // From Greg's code. Unnecessary but no harm.
  // interrupt Initialization [1] p 49
  GIMSK = 0x20;                                                // Global staging: Turns on pin interrupt capability [1] p200
  PCMSK = (1 << IPIN);                                      // Set IPIN to input-- interrupt (this is debounced button)
  // Shut Down ADC (Greg's Suggestion to save power)
  ADCSRA &= ~_BV(ADEN);                                      //if ADEN is on, turn off.
  // Enable interrupt
  sei();
}

void loop() {
  if (swtch) {
    SwitchStates();
  }
  analogWrite(OPIN, Flash?((4<<(State<<1))-1):0);
  if (State == 4) {
    FlashMode();
  }
  if (State == 0) {
    SleepMode();
  }
}

void SwitchStates(){
    State = (++State)%5;
    Flash = !(State == 0);
    swtch &= LOW;
}

void FlashMode(){
          now = micros();
      if (now - lastFlashTime > 250000) {
        Flash = !Flash;
        lastFlashTime = now;
      }
}

void SleepMode(){
      set_sleep_mode(SLEEP_MODE_PWR_DOWN);
      sleep_enable();
      sleep_cpu();
}

//Pin Change Interrupt Request 0 (don't look at nested interrupts)
ISR(PCINT0_vect) {
  // This will trigger on both rising and falling by default
  // need to read the state of the pin to tell if falling
      swtch |= !digitalRead(IPIN);
}

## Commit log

2018-09-22 Semester1Design
    Task: Build a light-device according to given specifications.
2018-09-26 Electronics 1
    Initial Schematic and Control Truth Table has been added
    [TruthTable.xlsx]
2018-09-29 Electrical 2: More Signals
    Added signal images to each part of the early-stage Block diagram
2018-10-28 Added Analog Schematic 1
    Tried to focus on using Resistor-Transistors. Future: Replace BJT with FET if possible. Look into Thyr gating. Find values. Elaborate on "Digital" components. Check math-- is osc chaotic?
2018-11-01 Added Secondary Schematic
    This one is my back up if all else falls through...
2018-11-10 PCB Itteration 1
    Still need to work on form factor, shape, and through hole geometry.
2018-11-10 Organization: PCB 1
    Renamed the preliminary PreStart copy to avoid confusion with the first itteration documents. Organized all PCB documents into one folder.
2018-11-14 ECAD Itteration2
    Replaced some components, updated through hole components and improved form factor.
    Plans:
    >Prog wires will be in braided band attached underneath board
    >Battery wires attaches on top but snakes through local holes to improve mechanical connection
    >LED connection has been left as a port to allow for form adaptability in the mechanical design
    > Edge of board will fit in groove within casing, and through holes will connect to posts (avoiding bolts and screws unless necessary)
    >battery holster will be under board
    > Electrical tape to insulate connections and keep wires in place.
    >Need to order Reflective tape, Lens?, silicone caulk and nail polish etc
    > Mechanical design soon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
    [2N7000.SchLib, ATTINY85-20SU.SchLib, CAPC2012X145N.PcbLib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]
2018-11-16 ECADItteration2
    removed reliefs from ground vias.
    [Connectors.SchLib, Discretes.SchLib, IC packages.PcbLib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]
2018-11-19 Mech 1
    Rough Main case
    Add:
    Battery case (and holes)
    LED (Front)
    Button and peg (top)
    Barbs and Ledge (Velcro and close body?)
    [5803305536.sldasm, 5803305728.sldasm, Board.sldprt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]
2018-11-22 Mech 2
    I'm building a casing out of 2 Altoid contrainers, soft velcro padding, and using potting to water proof and secure the board in a modular form. I will supply an power supply of 6xLR41 batteries (less readily accessible but longer lasting), which can power the system when outside of the case, as well as a converter to a 9V power supply (more readily accessible but shorter life).
    [9V.SLDPRT, Assem1.SLDASM, LargeAltoidsbox.SLDASM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]
2018-11-25 Mech Itteration Al
    -a v0.3.0
    orthogonal 2D (mechanical drawings) and a 3D rendering of your mechanical design has been added. I also have a physical model built confirm that this design would be feasible. Its a snug fit, but the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
    [Assem1.SLDASM, Board.sldprt, LargeAltoidsbox.SLDASM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]
2018-11-29 Final PCB
    Editted and Finalized PCB. Codde was also reupdated.
    [PCB1.PcbDoc, PCB1_SinglePlane.PcbDoc, SOT127P798X216-8N - Copy.PcbLib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]
2018-12-12 Updated Software and Awkward Hardware Demo 1
    Still debugging software. Tested Hardware with modified version of Greg's code. Spent too much time soldering and desoldering. The fumes got to me.
    Update: Video too large. Compressing and shortening the video
    [PCB_Project1.PrjPCB]
2018-12-13 Added More Demo stuff
    I added some more demo stuff and fixed some stuff
    [FlashLight.ino]
